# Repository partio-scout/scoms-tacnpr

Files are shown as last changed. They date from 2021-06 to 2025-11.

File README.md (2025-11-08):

# TACNPR project ('Neppari')

NPR-compatible (New Packet Radio) Ethernet-connected radio w/ integrated RF PA for the 70cm HAM band.
TACNPR is binary-compatible with the original design /1/ by Guillaume F4HDK.

Designed by Lasse OH3HZB & Tatu OH2EAT & Scoms team (special thanks to Mikko OH2FLO, Vili OH5GE and Tommi OH1GJV (TACBUCK design))

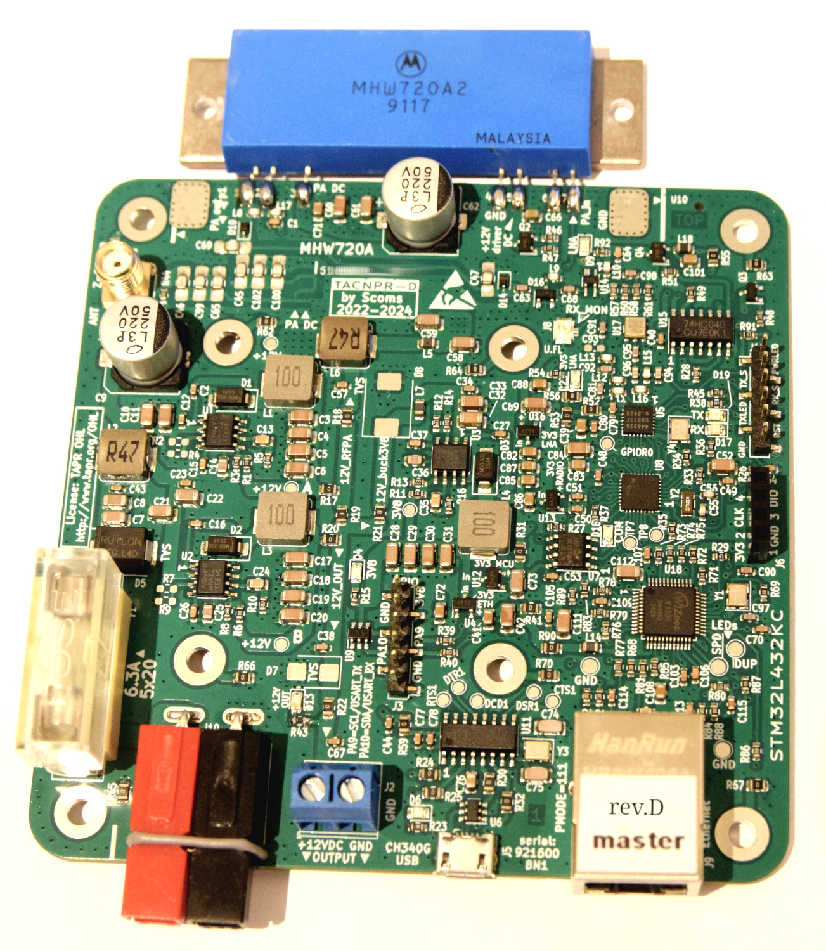
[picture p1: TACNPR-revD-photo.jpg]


Licensed under the TAPR Open Hardware License www.tapr.org/OHL

Please note that you need to be licensed HAM radio operator to use this radio. Remember to check your local regulations.

### Modifications for revA and revB to optimize RF performance

(these modifications are included in revC)

* C65 and C102: replace by 6p8
* C100: replace by 8p2

The tuning stub in revA/revB should be shorted according to the revC/revD layout.

### Project milestones and current status

* RevA: First version with Ethernet add-on module.
* RevB: Integrated Ethernet.
* RevC: RF performance enhancements (see the previous chapter). 
* RevD: Powerpole connector option added.
* RevE: TX/RX LEDs (J4)

RevC and RevD are tested and fully functional. RevA & RevB require tuning (stub) and modifications mentioned above. RevD->revE, no changes to RF section.

### Recommended TX power setting for maximum power with this PA module

set RF_power 55

/1/: NPR by Guillaume F4HDK (2018-): https://hackaday.io/project/164092-npr-new-packet-radio 

### Disclaimer

This design and all related material is provided as-is and is to be used at your own risk. The authors take no responsibility for any direct, indirect, incidental, or consequential 
damage that may arise from its use, including but not limited to damage to property, loss of data, or personal injury. Users are solely responsible for 
ensuring safe operation and adherence to all relevant laws and regulations. 

For the license terms, please refer to LICENSE file or http://www.tapr.org/OHL

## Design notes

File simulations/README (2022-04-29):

Qucs simulations for parts of the circuit

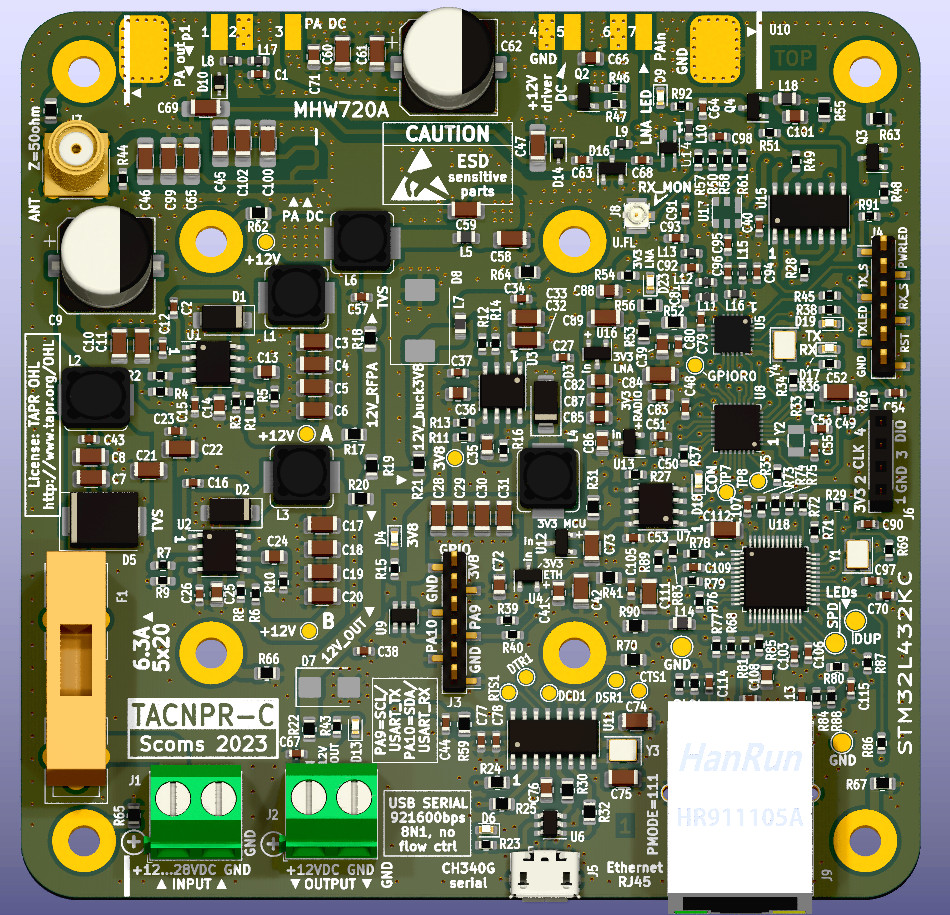
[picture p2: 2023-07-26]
TACNPR-revC-3D-top.jpg

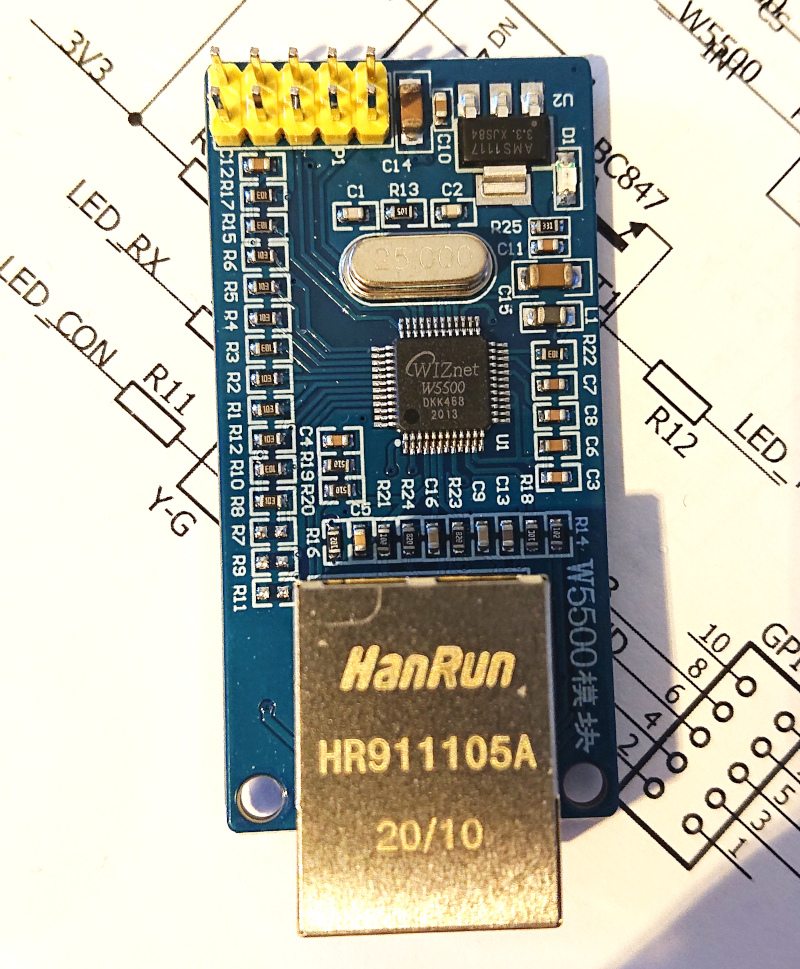
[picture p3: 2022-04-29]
w5500-module-photo-TACNPR-revA.JPG

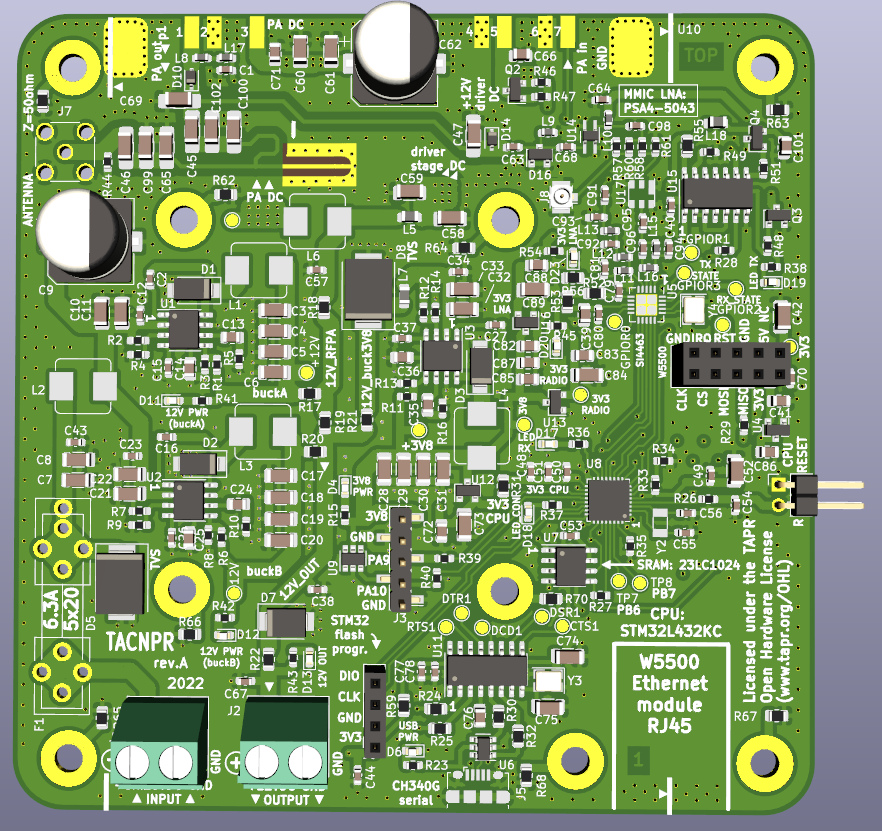
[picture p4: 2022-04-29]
TACNPR-revA-3D-top.jpg

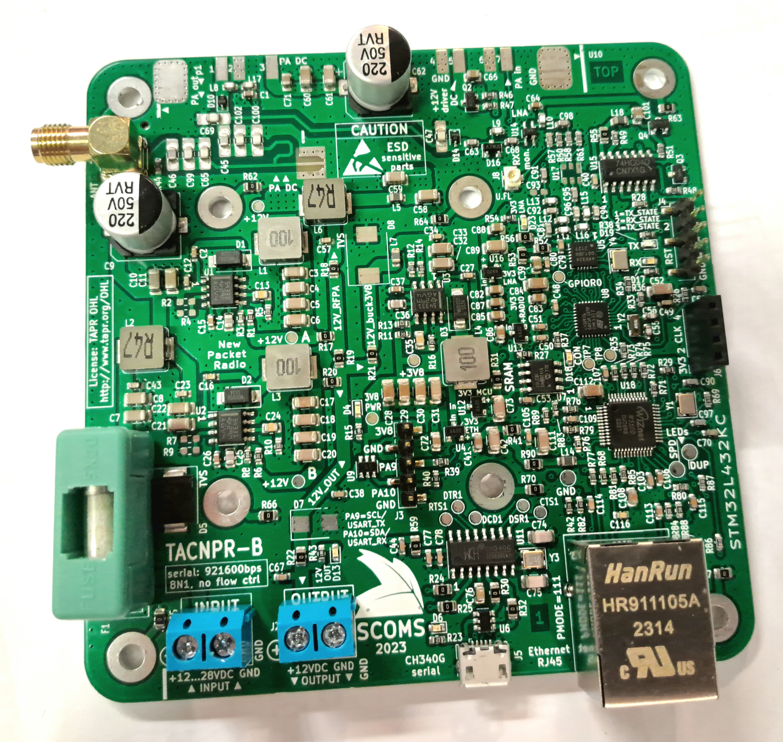
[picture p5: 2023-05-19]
TACNPR-revB-photo.jpg

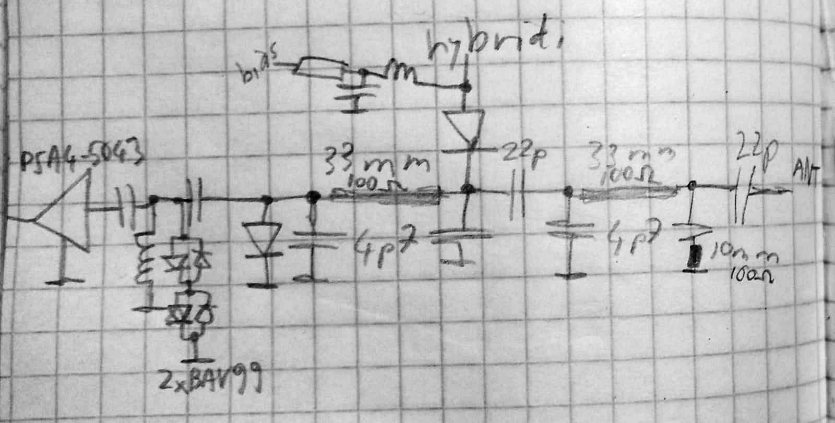
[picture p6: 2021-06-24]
rf-schema-oh2eat.jpg

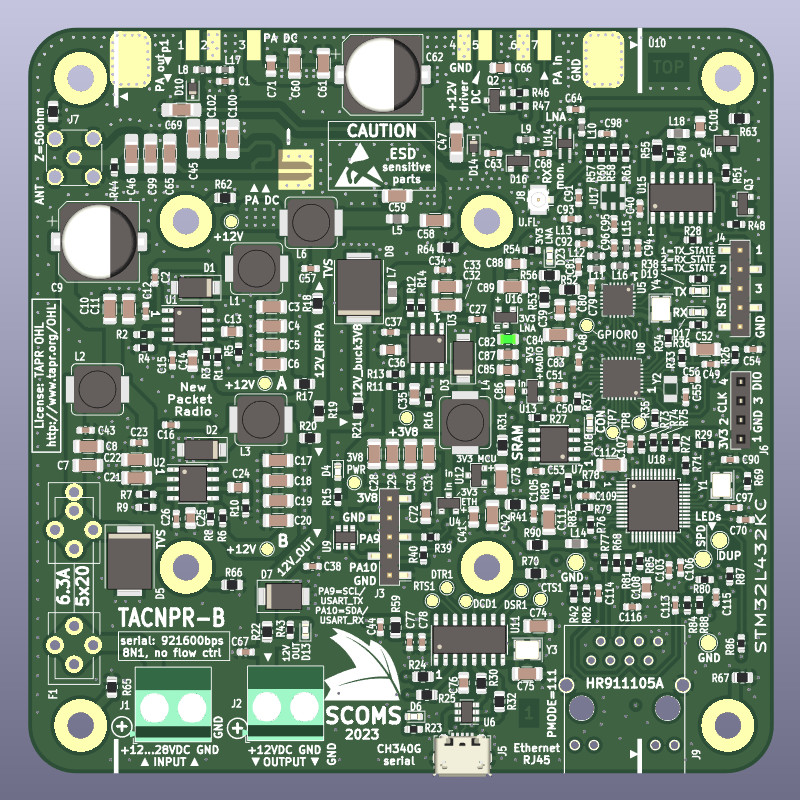
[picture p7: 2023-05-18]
TACNPR-revB-3D-top.jpg

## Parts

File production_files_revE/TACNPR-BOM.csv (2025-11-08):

Comment | Designator | Footprint | LCSC
8p2 | C100 | NPR:C_1206_0805_WIDE | C519996
4u7 | C108 | Capacitor_SMD:C_0805_2012Metric | C1779
6.8n | C114,C115 | Capacitor_SMD:C_0603_1608Metric | C1631
22n | C116 | Capacitor_SMD:C_0603_1608Metric | C21122
1n | C13,C24 | Capacitor_SMD:C_0805_2012Metric | C46653
10p | C14,C25,C36 | Capacitor_SMD:C_0805_2012Metric | C318752
10n | C1,C15,C26,C37,C64,C106,C113 | Capacitor_SMD:C_0603_1608Metric | C57112
22u | C3,C4,C5,C6,C17,C18,C19,C20,C28,C29,C30,C31,C42,C58,C59,C60,C61,C73,C84,C89 | Capacitor_SMD:C_1206_3216Metric | C12891
2n2 | C35 | Capacitor_SMD:C_0805_2012Metric | C1728
1u | C39,C41,C66,C71,C72,C82,C83,C85,C86,C87,C88,C101 | Capacitor_SMD:C_0805_2012Metric | C28323
100n | C2,C12,C16,C23,C27,C34,C38,C40,C43,C44,C48,C49,C50,C51,C53,C54,C57,C67,C70,C77,C78,C79,C80,C103,C105,C107,C109 | Capacitor_SMD:C_0603_1608Metric | C14663
10p | C45,C46 | NPR:C_1206_0805_WIDE | C597259
5p6 | C47,C69,C99 | NPR:C_1206_0805_WIDE | C513555
10u | C7,C8,C10,C11,C21,C22,C32,C33,C52,C111,C112 | Capacitor_SMD:C_1206_3216Metric | C13585
4p3 | C55,C56 | Capacitor_SMD:C_0603_1608Metric | C519108
6p8 | C65,C102 | NPR:C_1206_0805_WIDE | C519942
22p | C74,C75 | Capacitor_SMD:C_1206_3216Metric | C313096
470n | C76 | Capacitor_SMD:C_0805_2012Metric | C13967
100p | C81,C91,C95,C98 | Capacitor_SMD:C_0603_1608Metric | C14858
220u | C9,C62 | Capacitor_SMD:CP_Elec_10x10.5 | C125977
18p | C90,C97 | Capacitor_SMD:C_0603_1608Metric | C1647
10p | C63,C68,C92 | Capacitor_SMD:C_0603_1608Metric | C1634
DNP | C93 | Capacitor_SMD:C_0603_1608Metric_Pad1.08x0.95mm_HandSolder
3p3 | C94,C96 | Capacitor_SMD:C_0603_1608Metric | C1660
TestPoint | CTS1,DCD1,DSR1,DTR1,RTS1,TP7,TP8,TP10,TP12 | TestPoint:TestPoint_Pad_D1.5mm
SS34 | D1,D2,D3 | Diode_SMD:D_SMA | C8678
BA591 | D10,D14 | Diode_SMD:D_SOD-323 | C139448
BAV99 | D16 | Package_TO_SOT_SMD:SOT-23 | C2500
TX_LED | D19 | LED_SMD:LED_0805_2012Metric | C84256
3V3_LNA | D23 | LED_SMD:LED_0805_2012Metric | C2297
SMCJ28A | D5 | Diode_SMD:D_SMC | C10250
LED | D4,D6,D9,D13,D17,D18 | LED_SMD:LED_0805_2012Metric | C2297
TVS DIODE | D7 | Diode_SMD:D_SMB
TVS DIODE | D8 | Diode_SMD:D_SMC
5x20 fuse 6.3A | F1 | NPR:Fuseholder5x20_H_universal | C58066
GPIO_R1 | GPIOR0 | TestPoint:TestPoint_Pad_D1.5mm
MH | H1,H2,H3,H4,H5,H6,H7,H8 | MountingHole:MountingHole_3.5mm_Pad_TopBottom
PWR_TERM | J1,J2 | TerminalBlock_Phoenix:TerminalBlock_Phoenix_MKDS-1,5-2_1x02_P5.00mm_Horizontal | C474881
Powerpole | J10 | NPR:PowerPole_PP45_1336G1_1x2_Horizontal
GPIO_HEADER | J3 | Connector_PinHeader_2.54mm:PinHeader_1x06_P2.54mm_Vertical_SMD_Pin1Left | C5160789
GPIOR_HEADER | J4 | Connector_PinHeader_2.54mm:PinHeader_1x06_P2.54mm_Vertical_SMD_Pin1Left | C5160789
USB_B_Micro | J5 | Connector_USB:USB_Micro-B_Amphenol_10118194_Horizontal | C132563
PROG_CONN | J6 | Connector_PinSocket_2.54mm:PinSocket_1x04_P2.54mm_Vertical | C124413
SMA_F | J7 | Connector_Coaxial:SMA_Amphenol_132134_Vertical | C496549
U.fl | J8 | Connector_Coaxial:U.FL_Hirose_U.FL-R-SMT-1_Vertical | C88374
HR911105A | J9 | NPR:HR911105a | C12074
10u | L1,L3,L4 | Inductor_SMD:L_Bourns_SRP7028A_7.3x6.6mm | C132141
150n | L8,L10,L11,L17 | Inductor_SMD:L_0603_1608Metric | C15566
22n | L12 | Inductor_SMD:L_0603_1608Metric | C12099
15n | L9,L13 | Inductor_SMD:L_0603_1608Metric | C23651
47n | L15,L16 | Inductor_SMD:L_0603_1608Metric | C29683
470n | L2,L6 | Inductor_SMD:L_Bourns_SRP7028A_7.3x6.6mm | C285802
GZ2012D101TF | L5,L7,L14,L18 | Inductor_SMD:L_0805_2012Metric | C1015
10mm | NT1 | NetTie:NetTie-2_SMD_Pad0.5mm
2,5mm | NT2 | NPR:NetTie-2_longer_SMD_Pad0.5mm
10,5mm | NT3 | NetTie:NetTie-2_SMD_Pad0.5mm
AO3401A | Q2,Q4 | Package_TO_SOT_SMD:SOT-23 | C15127
MMBT3904 | Q3 | Package_TO_SOT_SMD:SOT-23 | C20526
10k 1% | R1,R6,R11 | Resistor_SMD:R_0603_1608Metric | C25804
330k | R12 | Resistor_SMD:R_0603_1608Metric | C23137
2k7 | R13 | Resistor_SMD:R_0603_1608Metric | C13167
100k | R14,R44 | Resistor_SMD:R_0603_1608Metric | C25803
DNP | R2,R4,R7,R9 | Resistor_SMD:R_0603_1608Metric_Pad0.98x0.95mm_HandSolder
1.5k | R15,R23,R36,R37,R38,R49,R54,R92 | Resistor_SMD:R_0603_1608Metric | C118397
330 | R26,R27,R29,R45,R91,R93,R94 | Resistor_SMD:R_0603_1608Metric | C23138
68 | R28,R57 | Resistor_SMD:R_0603_1608Metric | C27592
715R | R3,R8 | Resistor_SMD:R_0603_1608Metric | C23238
10k | R16,R33,R34,R35,R46,R47,R48,R51,R71,R72,R73,R74,R75 | Resistor_SMD:R_0603_1608Metric | C25804
100 1% | R39,R40,R42,R68,R81,R82,R83,R84,R88,R89 | Resistor_SMD:R_0603_1608Metric | C22775
4k7 | R43 | Resistor_SMD:R_0603_1608Metric | C23162
30k | R5,R10 | Resistor_SMD:R_0603_1608Metric | C22984
0 | R17,R18,R19,R20,R21,R22,R24,R25,R30,R31,R32,R41,R50,R52,R53,R55,R56,R59,R62,R63,R64,R65,R66,R67,R70,R90 | Resistor_SMD:R_0805_2012Metric | C17477
22 | R58 | Resistor_SMD:R_0603_1608Metric | C23345
220 | R60,R61 | Resistor_SMD:R_0603_1608Metric | C22962
1M | R69 | Resistor_SMD:R_0603_1608Metric | C22935
12.4k 1% | R76 | Resistor_SMD:R_0603_1608Metric | C227572
33 | R77,R78,R79,R80 | Resistor_SMD:R_0603_1608Metric | C23140
10 1% | R85 | Resistor_SMD:R_0603_1608Metric | C22859
1k | R86,R87 | Resistor_SMD:R_0603_1608Metric | C21190
TestPoint | TP1,TP4,TP5,TP6 | TestPoint:TestPoint_Pad_D2.0mm
BA_12V | TP11 | TestPoint:TestPoint_Pad_D1.5mm
BB_12V | TP2 | TestPoint:TestPoint_Pad_D1.5mm
BC_3V8 | TP3 | TestPoint:TestPoint_Pad_D1.5mm
CONL | TP9 | TestPoint:TestPoint_Pad_D1.5mm
TPS54331DR | U1,U2,U3 | Package_SO:SOIC-8_3.9x4.9mm_P1.27mm | C9865
MHW720A | U10 | NPR:MHW720A
CH340G | U11 | Package_SO:SOIC-16_3.9x9.9mm_P1.27mm | C14267
PSA4-5043 (SPF5043Z) | U14 | NPR:SOT-343_SC-70-4-widepad_Handsoldering | C470902
74HC04 | U15 | Package_SO:SOIC-14_3.9x8.7mm_P1.27mm | C86613
B39431B3710U410 | U17 | NPR:DCC6C
W5500 | U18 | Package_QFP:LQFP-48_7x7mm_P0.5mm | C32843
XC6206PxxxMR | U4,U12,U13,U16 | Package_TO_SOT_SMD:SOT-23 | C5446
Si4463 | U5 | Package_DFN_QFN:QFN-20-1EP_4x4mm_P0.5mm_EP2.6x2.6mm_ThermalVias | C476202
SRV05-4 | U6,U9 | Package_TO_SOT_SMD:SOT-23-6 | C85364
23LC1024 | U7 | Package_SO:SOIC-8_3.9x4.9mm_P1.27mm
STM32L432KC | U8 | Package_DFN_QFN:QFN-32-1EP_5x5mm_P0.5mm_EP3.45x3.45mm | C1337280
25 MHz | Y1 | Crystal:Crystal_SMD_3225-4Pin_3.2x2.5mm | C9006
32.768K | Y2 | Crystal:Crystal_SMD_3215-2Pin_3.2x1.5mm | C32346
12M | Y3 | Crystal:Crystal_SMD_SeikoEpson_TSX3225-4Pin_3.2x2.5mm | C9002
30M | Y4 | Crystal:Crystal_SMD_SeikoEpson_TSX3225-4Pin_3.2x2.5mm | C2149121

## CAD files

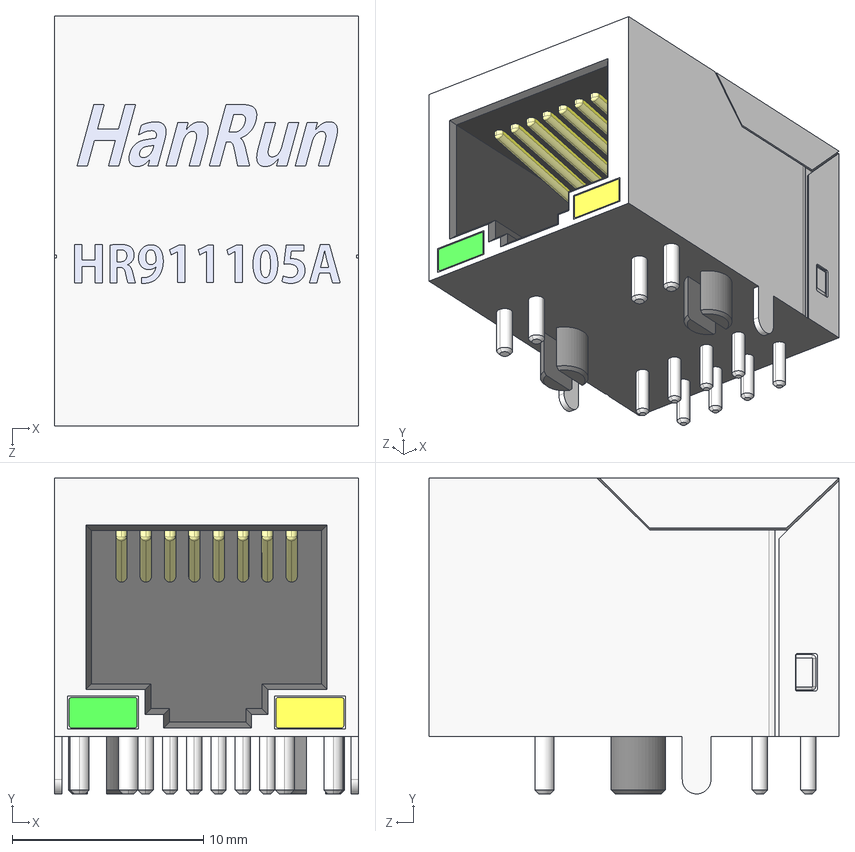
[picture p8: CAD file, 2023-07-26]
HR911105A.STEP
15.9 x 16.5 x 21.4 mm

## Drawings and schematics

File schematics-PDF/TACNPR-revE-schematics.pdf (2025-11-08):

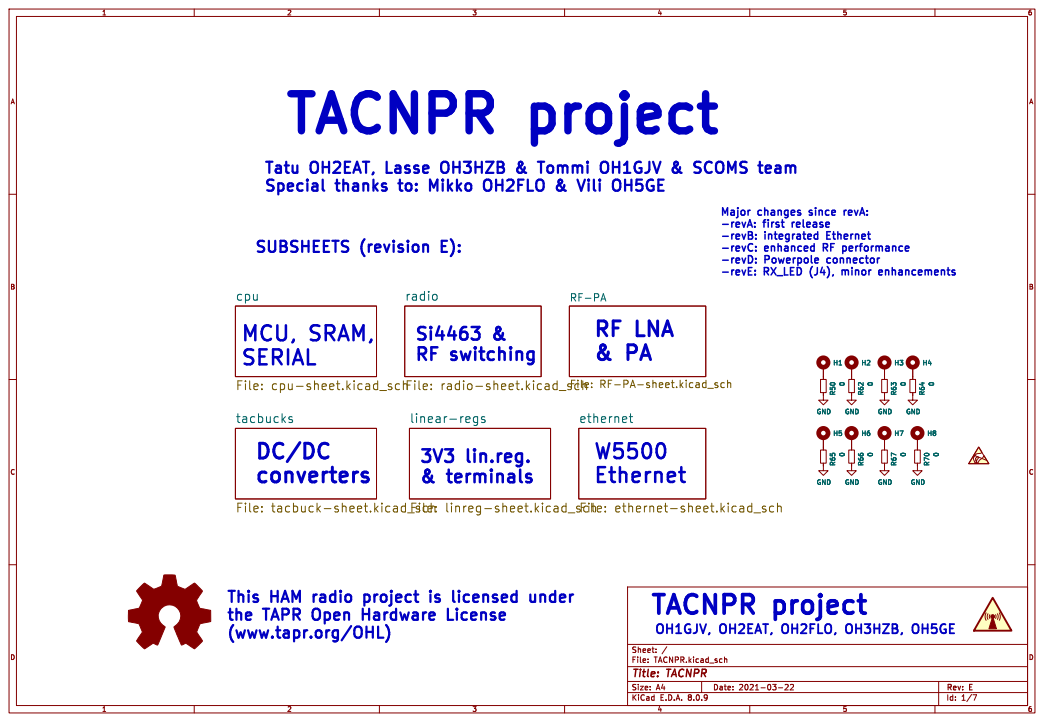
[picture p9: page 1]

Tatu OH2EAT, Lasse OH3HZB & Tommi OH1GJV & SCOMS team
Special thanks to: Mikko OH2FLO & Vili OH5GE

Major changes since revA:

File: RF-PA-sheet.kicad_sch

This HAM radio project is licensed under
the TAPR Open Hardware License
(www.tapr.org/OHL)

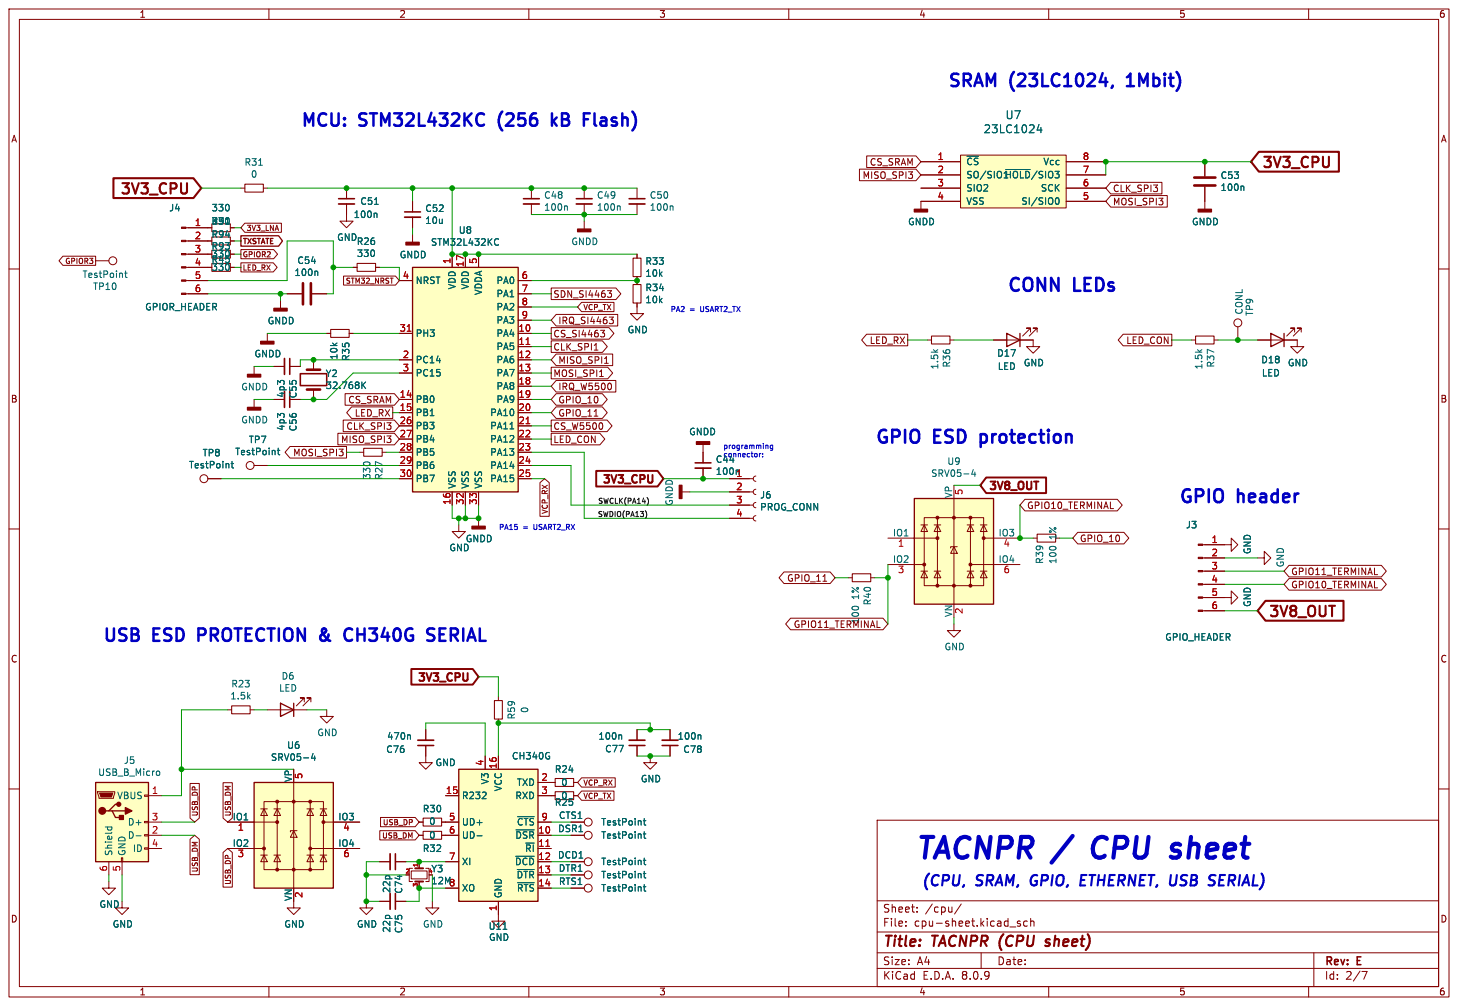
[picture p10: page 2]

1 PA4 10 PA5 11 PA6 12 PA7 13 PB0 14 PB1 15 VSS 16 VDD 17 PA8 18 PA9 19 PC14 2 PA10 20 PA11 21 PA12 22 PA13 23 PA14 24 PA15 25 PB3 26 PB4 27 PB5 28 PB6 29 PC15 3 PB7 30 PH3 31 VSS 32 VSS 33 NRST 4 VDDA

connector: PA2 = USART2_TX USB ESD PROTECTION & CH340G SERIAL

4 UD+ 5 UD- 6 XI 7 XO 8 ~{CTS}9 U11 CH340G
0 GND

4 UD+ 5 UD- 6 XI 7 XO 8 ~{CTS}9 R32

1 ~{DSR} 10 ~{RI} 11 ~{DCD} 12 ~{DTR} 13 ~{RTS} 14 R232 15 VCC 16 TXD 2 RXD 3 V3

Id: 2/7 Title: TACNPR (CPU sheet) File: cpu-sheet.kicad_sch Sheet: /cpu/ 1

(CPU, SRAM, GPIO, ETHERNET, USB SERIAL)

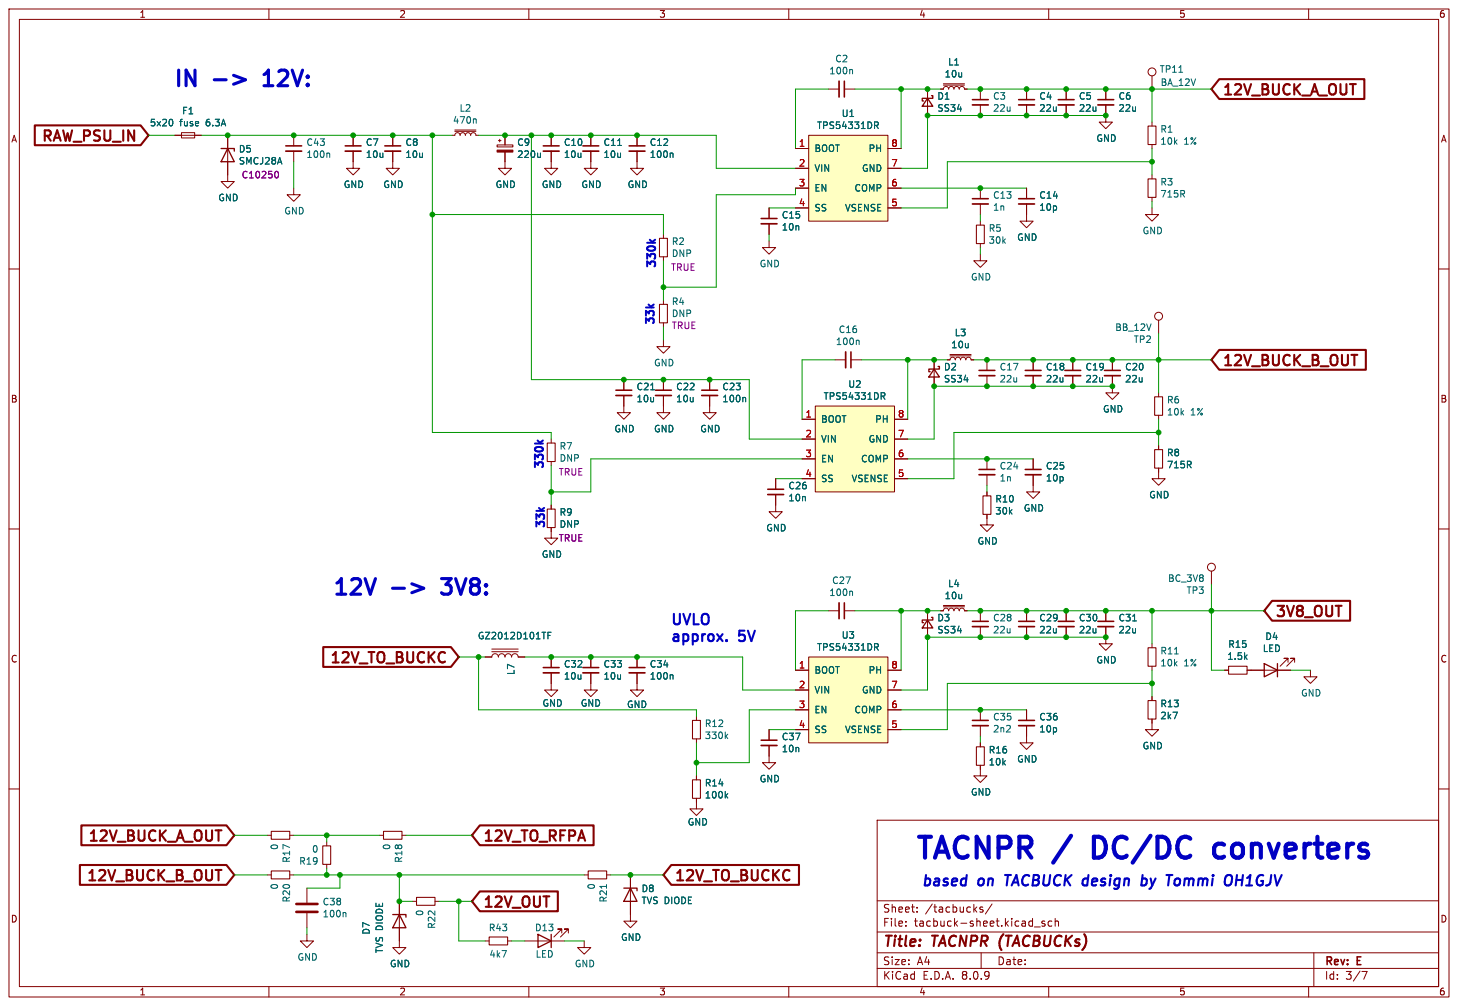
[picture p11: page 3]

TRUE GND D7 TVS DIODE GND

Id: 3/7 Title: TACNPR (TACBUCKs) File: tacbuck-sheet.kicad_sch Sheet: /tacbucks/ GND

TACNPR / DC/DC converters

based on TACBUCK design by Tommi OH1GJV

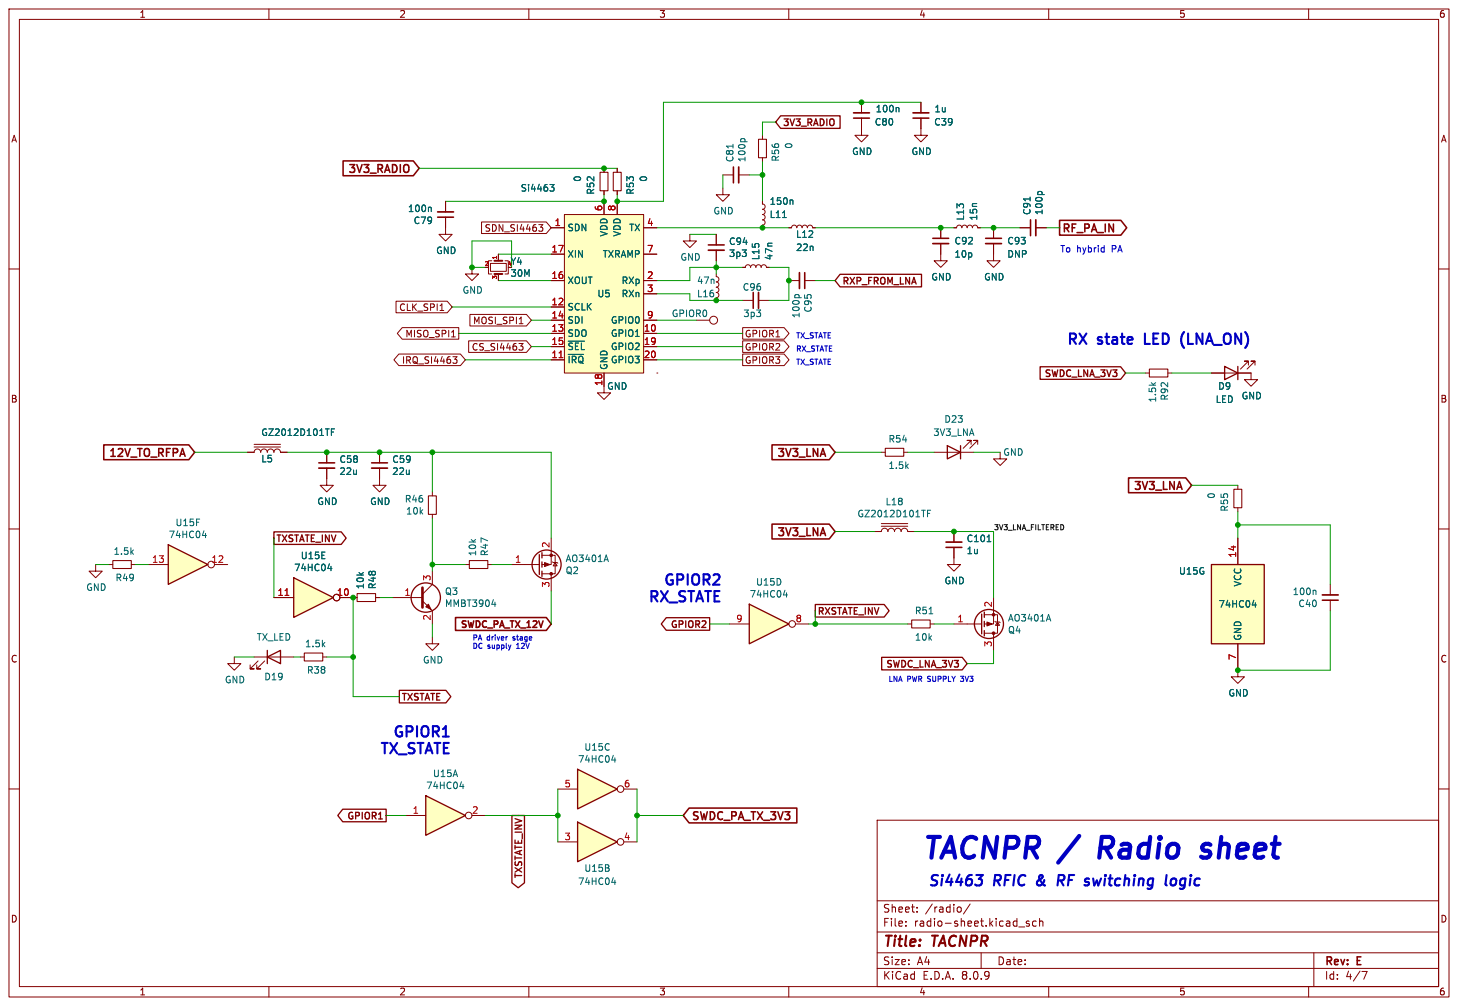
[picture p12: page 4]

File: radio-sheet.kicad_sch Sheet: /radio/ R46

Si4463 RFIC & RF switching logic

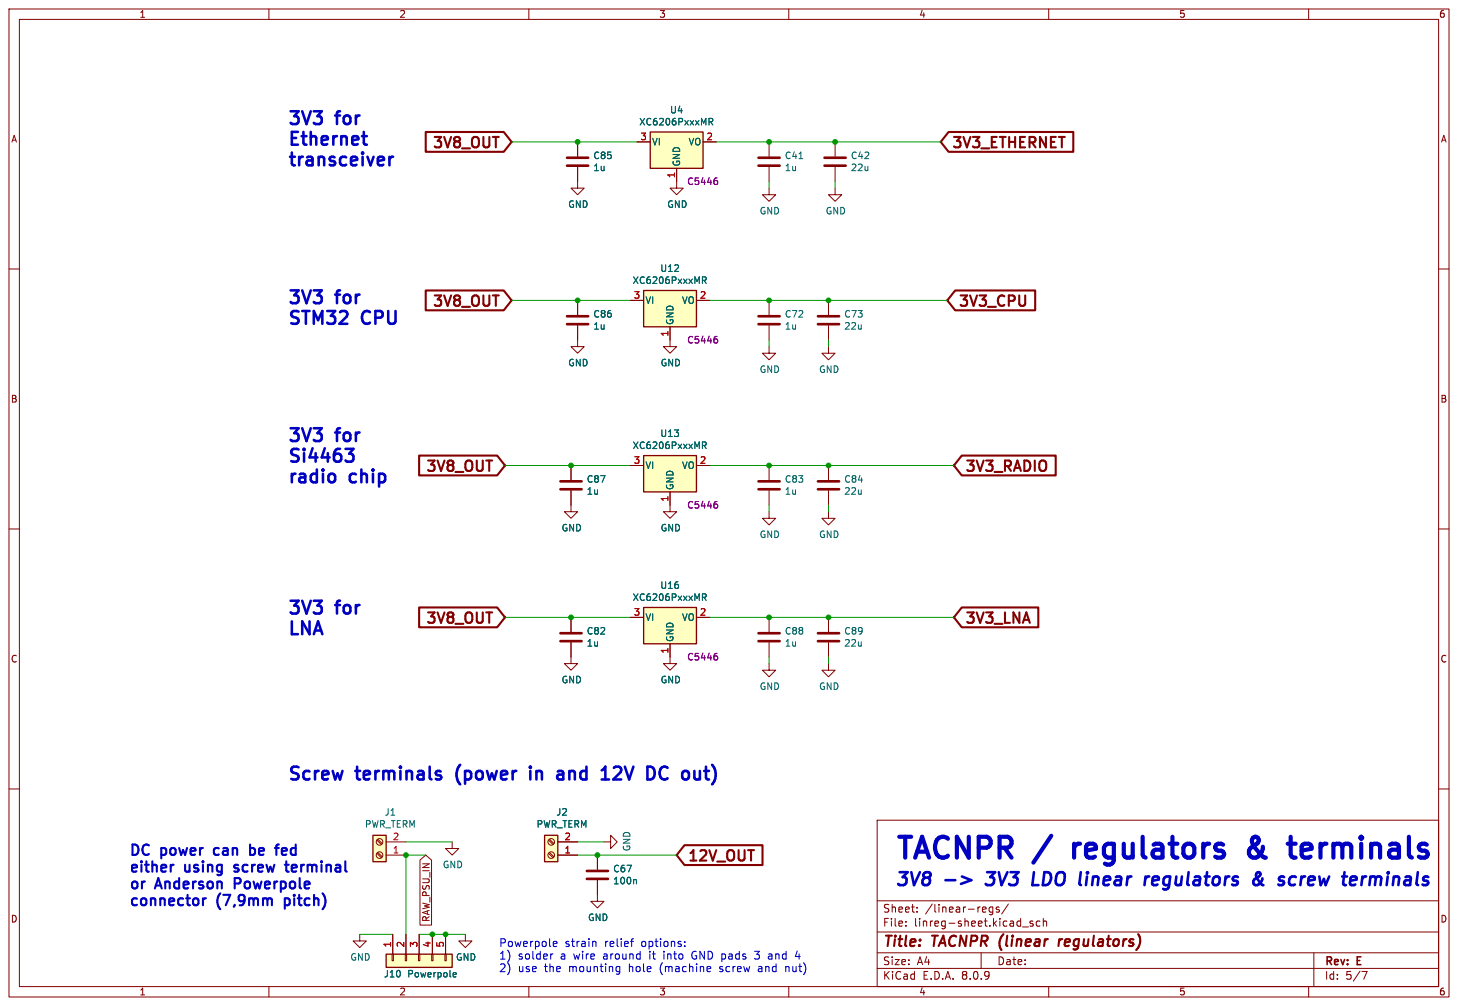
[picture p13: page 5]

1 VO 2 VI 3 GND GND
1u GND
22u GND GND

DC power can be fed
either using screw terminal or Anderson Powerpole

Id: 5/7 Title: TACNPR (linear regulators) File: linreg-sheet.kicad_sch Sheet: /linear-regs/

2) use the mounting hole (machine screw and nut) J10 Powerpole

Powerpole strain relief options:
1) solder a wire around it into GND pads 3 and 4

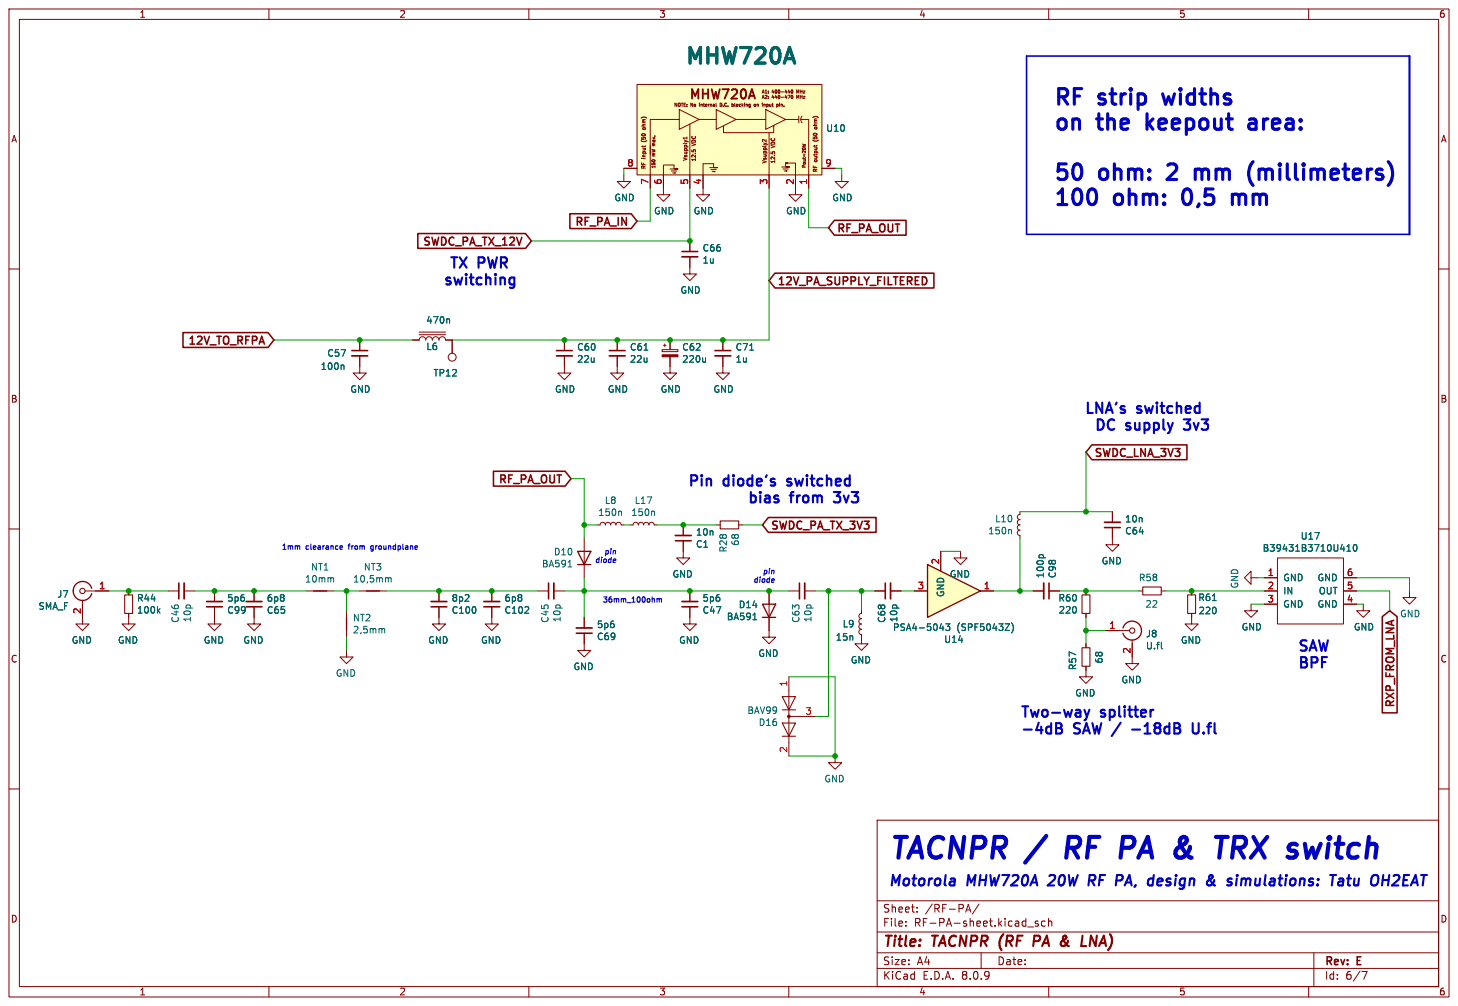
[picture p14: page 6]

RF strip widths
on the keepout area:

Id: 6/7 Title: TACNPR (RF PA & LNA) File: RF-PA-sheet.kicad_sch Sheet: /RF-PA/

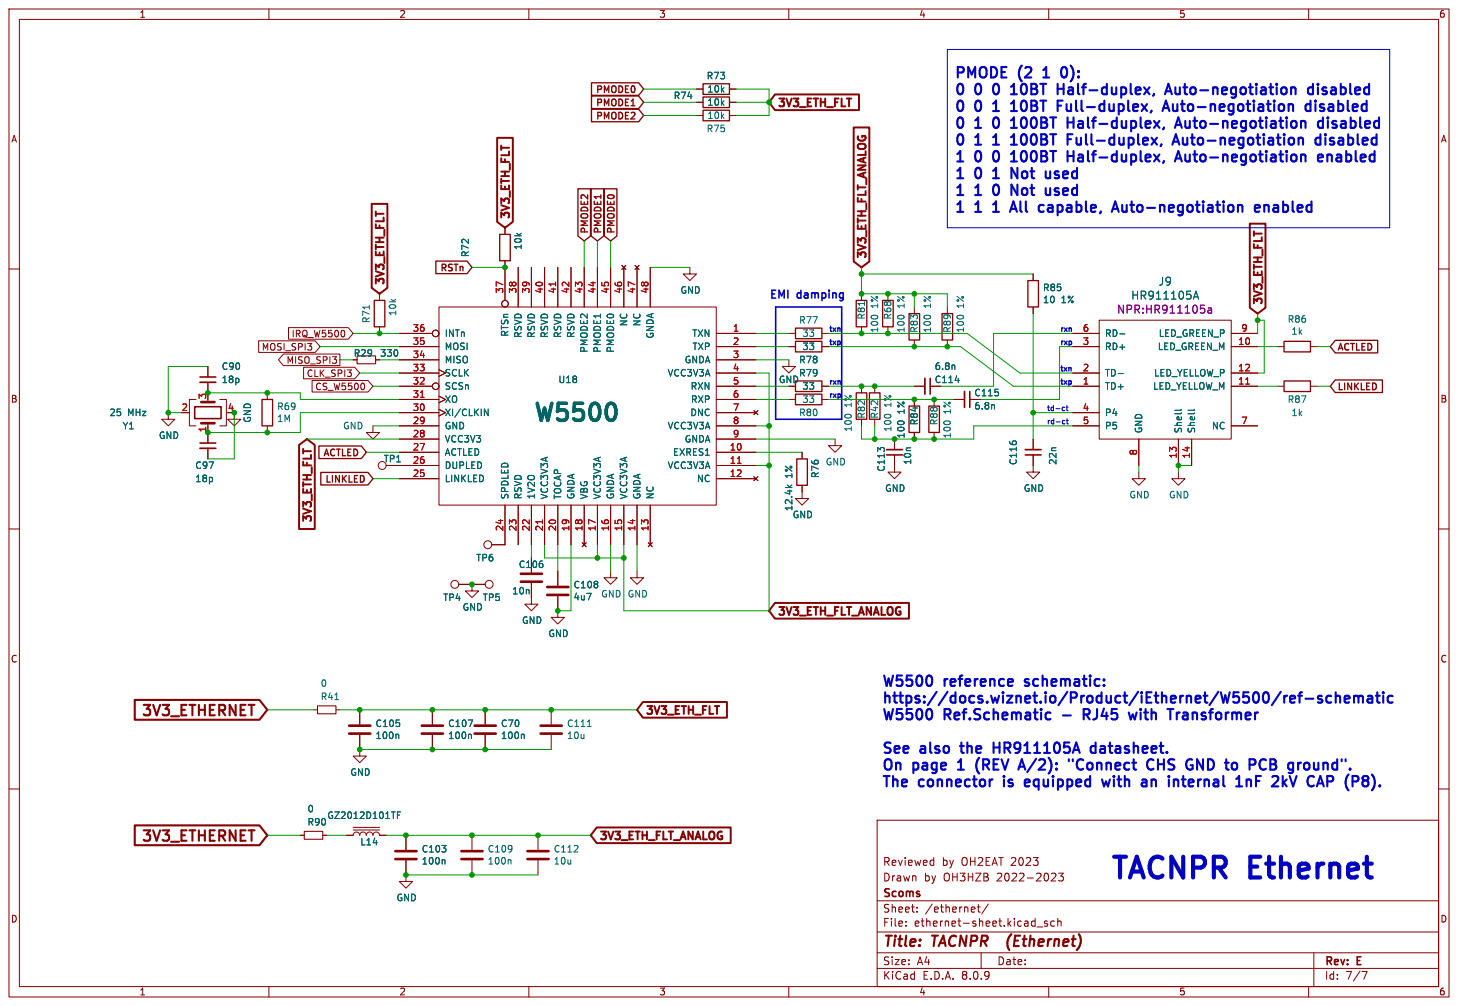
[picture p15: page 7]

td-ct rd-ct PMODE (2 1 0):
1 0 1 Not used
1 1 0 Not used

https://docs.wiznet.io/Product/iEthernet/W5500/ref-schematic

The connector is equipped with an internal 1nF 2kV CAP (P8).

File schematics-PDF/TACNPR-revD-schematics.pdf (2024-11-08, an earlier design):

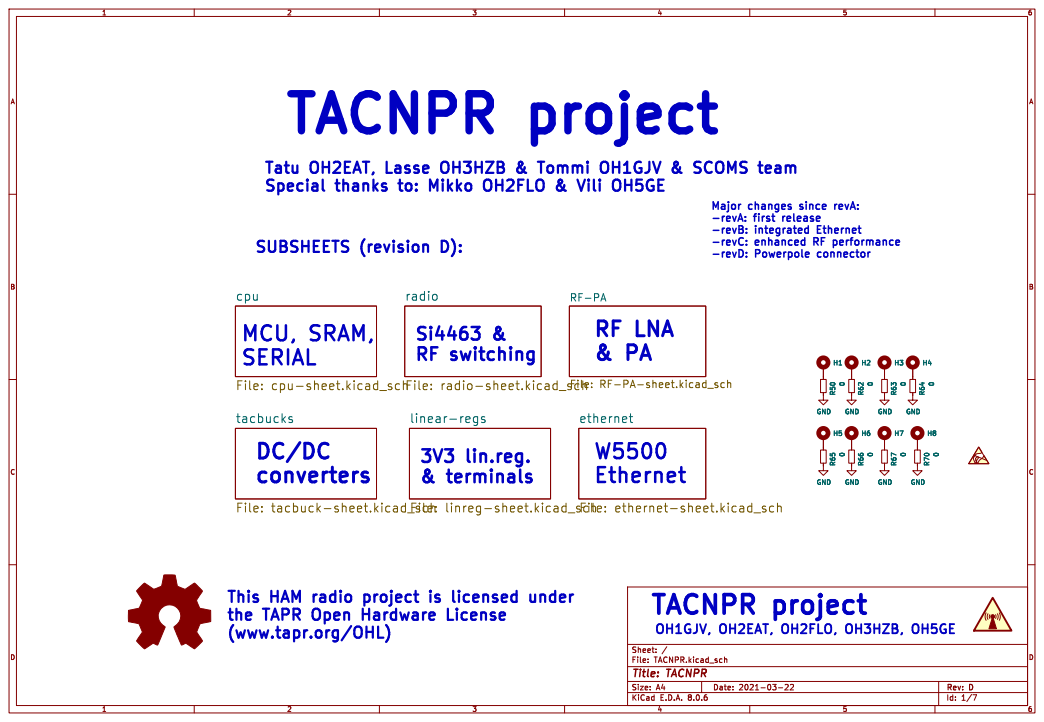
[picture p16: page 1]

Tatu OH2EAT, Lasse OH3HZB & Tommi OH1GJV & SCOMS team
Special thanks to: Mikko OH2FLO & Vili OH5GE

Major changes since revA:

File: TACNPR.kicad_sch Sheet: / cpu
MCU, SRAM,
SERIAL

File: RF-PA-sheet.kicad_sch

(www.tapr.org/OHL)

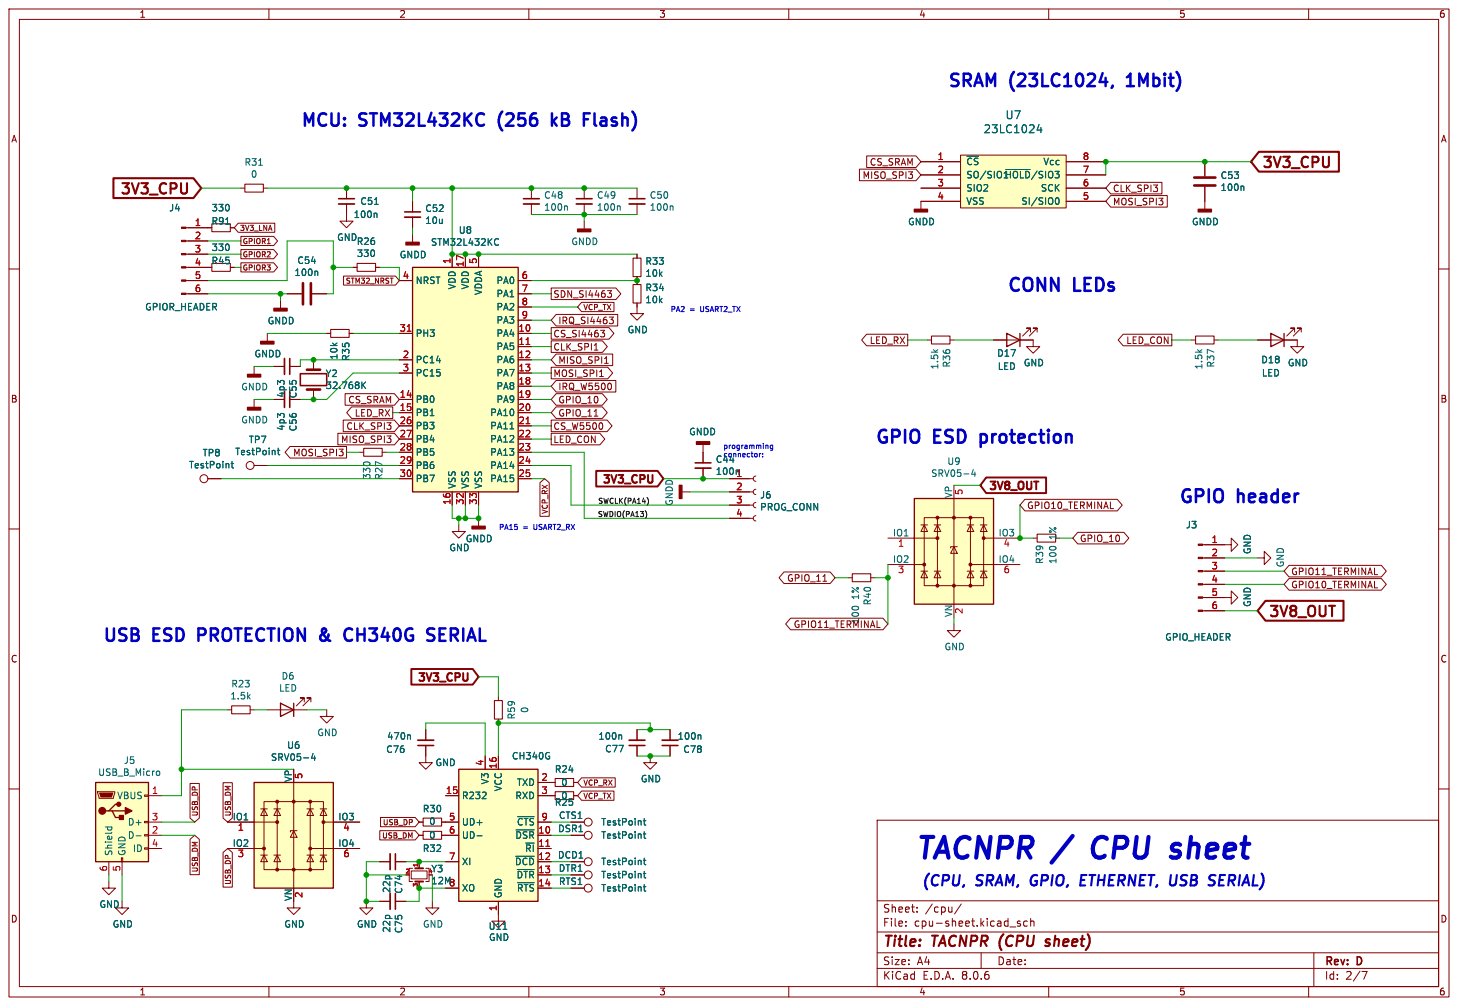
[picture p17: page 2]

1 PA4 10 PA5 11 PA6 12 PA7 13 PB0 14 PB1 15 VSS 16 VDD 17 PA8 18 PA9 19 PC14 2 PA10 20 PA11 21 PA12 22 PA13 23 PA14 24 PA15 25 PB3 26 PB4 27 PB5 28 PB6 29 PC15 3 PB7 30 PH3 31 VSS 32 VSS 33 NRST 4 VDDA

USB ESD PROTECTION & CH340G SERIAL

4 UD+ 5 UD- 6 XI 7 XO 8 ~{CTS}9 U11 CH340G
0 GND

4 UD+ 5 UD- 6 XI 7 XO 8 ~{CTS}9 GND 22p C74 22p C75 Y3

1 ~{DSR} 10 ~{RI} 11 ~{DCD} 12 ~{DTR} 13 ~{RTS} 14 R232 15 VCC 16 TXD 2 RXD 3 V3

Id: 2/7 Title: TACNPR (CPU sheet) File: cpu-sheet.kicad_sch Sheet: /cpu/ R24

(CPU, SRAM, GPIO, ETHERNET, USB SERIAL)

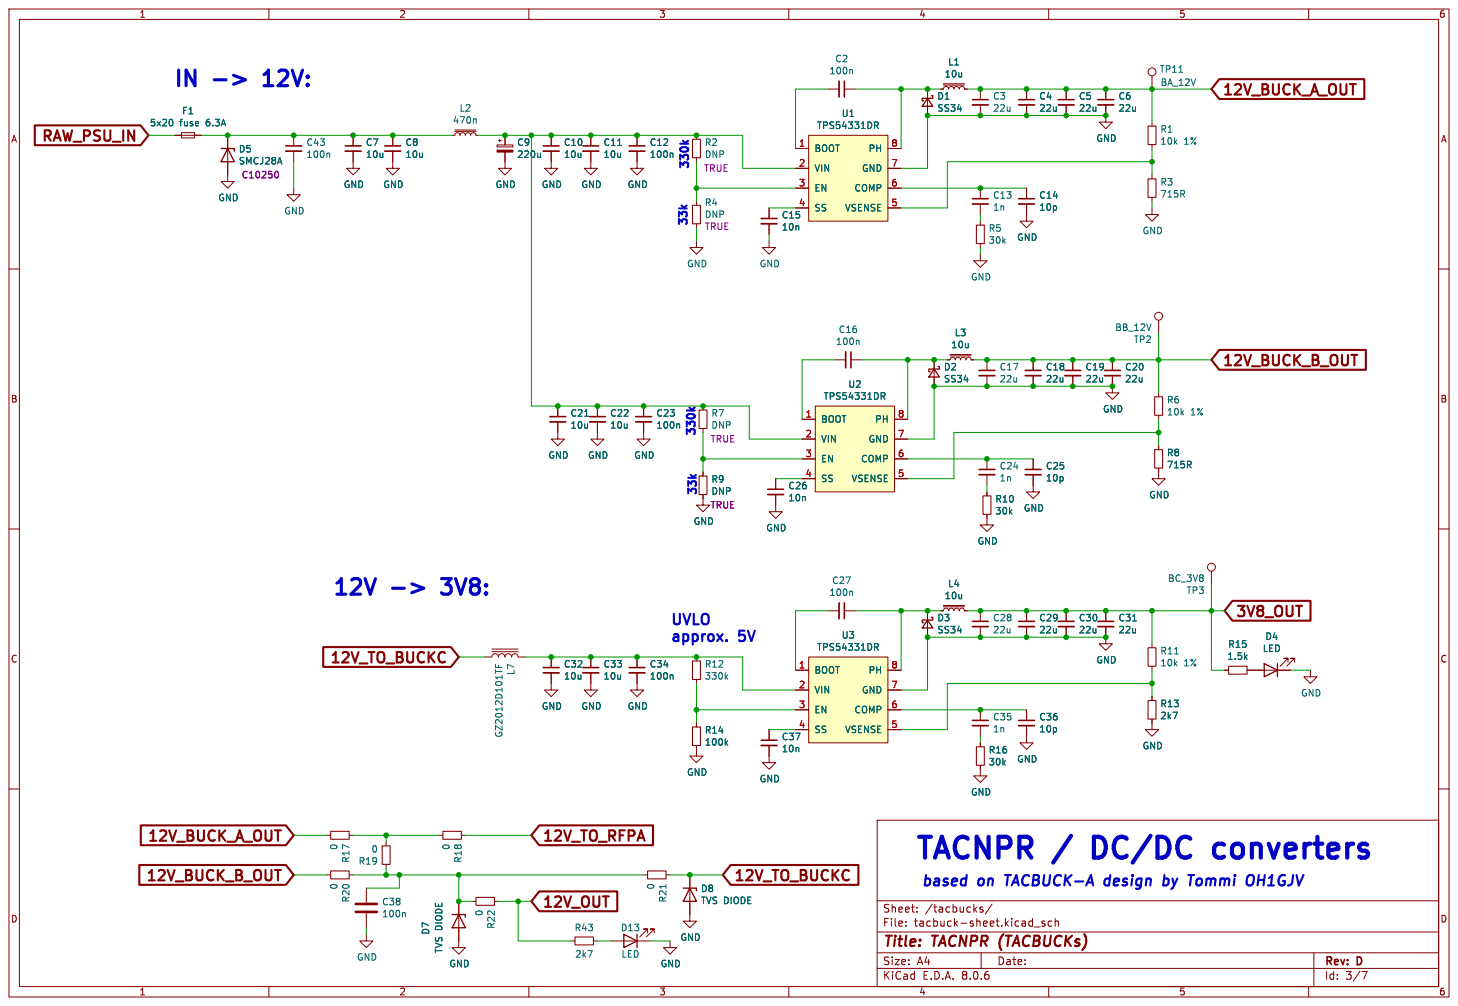
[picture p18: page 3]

TACNPR / DC/DC converters

based on TACBUCK-A design by Tommi OH1GJV

Id: 3/7 Title: TACNPR (TACBUCKs) File: tacbuck-sheet.kicad_sch Sheet: /tacbucks/

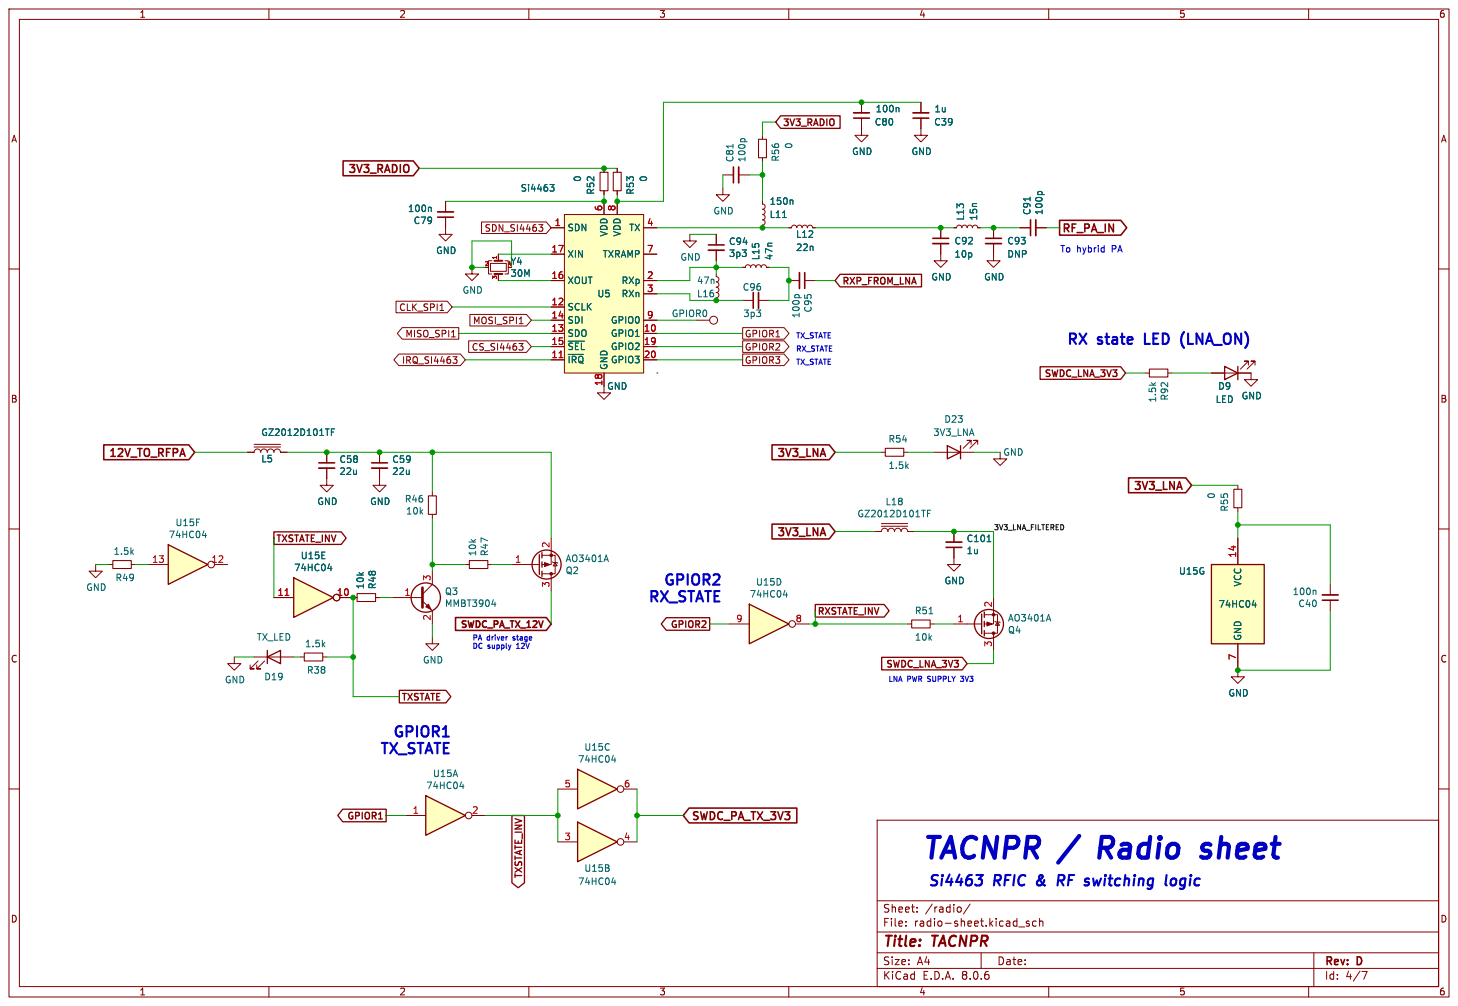
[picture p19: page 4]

File: radio-sheet.kicad_sch Sheet: /radio/ R46

Si4463 RFIC & RF switching logic

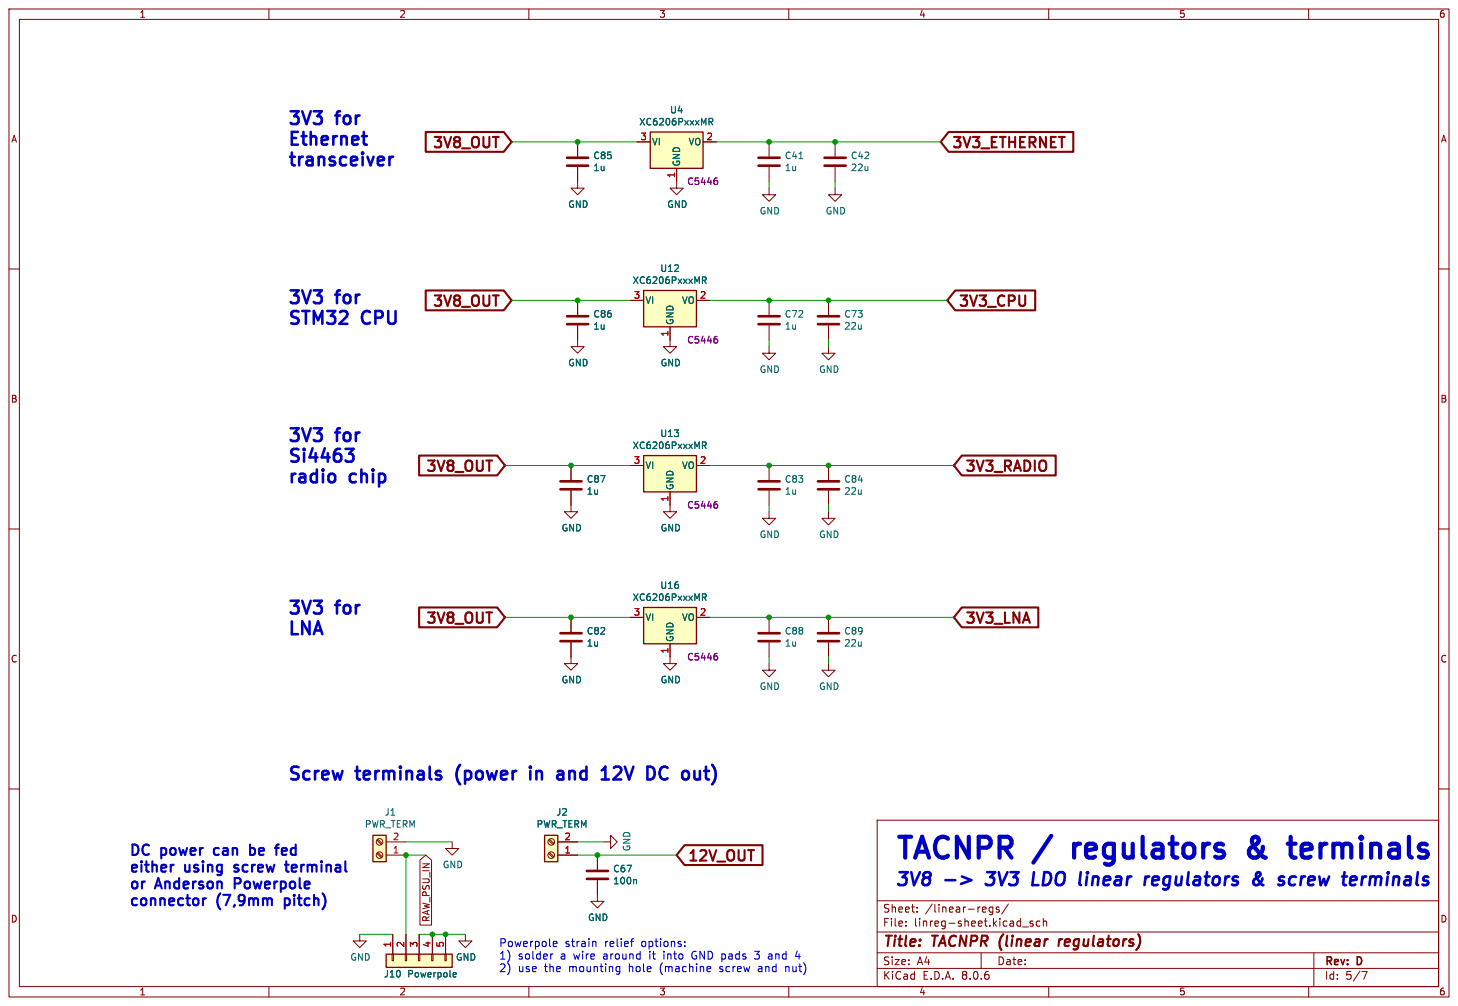
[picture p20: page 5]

1 VO 2 VI 3 GND GND
C5446 GND

DC power can be fed
either using screw terminal or Anderson Powerpole

Id: 5/7 Title: TACNPR (linear regulators) File: linreg-sheet.kicad_sch Sheet: /linear-regs/

2) use the mounting hole (machine screw and nut) J10 Powerpole

Powerpole strain relief options:
1) solder a wire around it into GND pads 3 and 4


RF strip widths
on the keepout area:

TACNPR / RF PA & TRX switch


td-ct rd-ct PMODE (2 1 0):
1 0 1 Not used
1 1 0 Not used

https://docs.wiznet.io/Product/iEthernet/W5500/ref-schematic

The connector is equipped with an internal 1nF 2kV CAP (P8).

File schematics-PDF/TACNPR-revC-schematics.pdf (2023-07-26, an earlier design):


File: RF-PA-sheet.kicad_sch

(www.tapr.org/OHL)


1 PA4 10 PA5 11 PA6 12 PA7 13 PB0 14 PB1 15 VSS 16 VDD 17 PA8 18 PA9 19 PC14 2 PA10 20 PA11 21 PA12 22 PA13 23 PA14 24 PA15 25 PB3 26 PB4 27 PB5 28 PB6 29 PC15 3 PB7 30 PH3 31 VSS 32 VSS 33 NRST 4 VDDA

USB ESD PROTECTION & CH340G SERIAL

4 UD+ 5 UD- 6 XI 7 XO 8 ~{CTS}9 U11 CH340G
0 GND

4 UD+ 5 UD- 6 XI 7 XO 8 ~{CTS}9 GND 22p C74 22p C75 Y3

1 ~{DSR} 10 ~{RI} 11 ~{DCD} 12 ~{DTR} 13 ~{RTS} 14 R232 15 VCC 16 TXD 2 RXD 3 V3

Id: 2/7 Title: TACNPR (CPU sheet) File: cpu-sheet.kicad_sch Sheet: /cpu/ R24

(CPU, SRAM, GPIO, ETHERNET, USB SERIAL)


TACNPR / DC/DC converters

based on TACBUCK-A design by Tommi OH1GJV


File: radio-sheet.kicad_sch Sheet: /radio/ R46

Si4463 RFIC & RF switching logic


1 VO 2 VI 3 GND GND
1u GND GND

Id: 5/7 Title: TACNPR (linear regulators) File: linreg-sheet.kicad_sch Sheet: /linear-regs/


RF strip widths
on the keepout area:

TACNPR / RF PA & TRX switch


td-ct rd-ct PMODE (2 1 0):
1 0 1 Not used
1 1 0 Not used

https://docs.wiznet.io/Product/iEthernet/W5500/ref-schematic

The connector is equipped with an internal 1nF 2kV CAP (P8).

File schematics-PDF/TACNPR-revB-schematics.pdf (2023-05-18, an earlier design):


Tatu OH2EAT, Lasse OH3HZB & Tommi OH1GJV & SCOMS team
Special thanks to: Mikko OH2FLO & Vili OH5GE

SUBSHEETS (revB with onboard Ethernet):

File: RF-PA-sheet.kicad_sch

This HAM radio project is licensed under
the TAPR Open Hardware License
(www.tapr.org/OHL)


1 PA4 10 PA5 11 PA6 12 PA7 13 PB0 14 PB1 15 VSS 16 VDD 17 PA8 18 PA9 19 PC14 2 PA10 20 PA11 21 PA12 22 PA13 23 PA14 24 PA15 25 PB3 26 PB4 27 PB5 28 PB6 29 PC15 3 PB7 30 PH3 31 VSS 32 VSS 33 NRST 4 VDDA

USB ESD PROTECTION & CH340G SERIAL

4 UD+ 5 UD- 6 XI 7 XO 8 ~{CTS} 9 U11 CH340G

1 ~{DSR}10 ~{RI}11 ~{DCD}12 ~{DTR}13 ~{RTS}14 R232 15 VCC 16 TXD 2 RXD 3 V3

(CPU, SRAM, GPIO, ETHERNET, USB SERIAL)

File: cpu-sheet.kicad_sch
Id: 2/7 Title: TACNPR (CPU sheet)


File: tacbuck-sheet.kicad_sch Sheet: /tacbucks/ C33

TACNPR / DC/DC converters

based on TACBUCK-A design by Tommi OH1GJV

Id: 3/7 Title: TACNPR (TACBUCKs)


PA driver stage DC supply 12V

Si4463 RFIC & RF switching logic


TACNPR / regulators & terminals
3V8 -> 3V3 LDO linear regulators & screw terminals

Sheet: /linear-regs/
File: linreg-sheet.kicad_sch
Id: 5/7 Title: TACNPR (linear regulators)


RF strip widths
on the keepout area:

File: RF-PA-sheet.kicad_sch Sheet: /RF-PA/ L9

TACNPR / RF PA & TRX switch

Id: 6/7 Title: TACNPR (RF PA & LNA)


rd-ct PMODE (2 1 0):
0 0 0 10BT Half-duplex, Auto-negotiation disabled
0 0 1 10BT Full-duplex, Auto-negotiation disabled

0 1 0 100BT Half-duplex, Auto-negotiation disabled
0 1 1 100BT Full-duplex, Auto-negotiation disabled
1 0 0 100BT Half-duplex, Auto-negotiation enabled
1 0 1 Not used
1 1 0 Not used
1 1 1 All capable, Auto-negotiation enabled

W5500 reference schematic:
https://docs.wiznet.io/Product/iEthernet/W5500/ref-schematic
W5500 Ref.Schematic - RJ45 with Transformer

See also the HR911105A datasheet.
On page 1 (REV A/2): "Connect CHS GND to PCB ground".
The connector is equipped with an internal 1nF 2kV CAP (P8).

File: ethernet-sheet.kicad_sch Sheet: /ethernet/ Scoms Drawn by OH3HZB 2022-2023

Id: 7/7 Title: TACNPR (Ethernet)

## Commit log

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2021-03-25 fix typo Si4633 -> Si4463
    [TACNPR.sch, radio-sheet.sch]
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2021-03-30 si4463 is module not chip pinout in NPR, we have to be careful..
    [radio-sheet.sch]
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2021-04-01 meeting 1.4.2021 notes, Hanrun RJ45 connector added to lib, buck layout to be enhanced
    [TACNPR.kicad_pcb, TACNPR.sch, cpu-sheet.sch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]
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2021-04-03 ESD prot. comp. should be changed (jlc basic)
    [cpu-sheet.sch]
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2021-04-04 a few corrections to coil placements
    [TACNPR.kicad_pcb]
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2021-04-08 remove USB connector, pins not compatible with NPR FW
    [TACNPR.kicad_pcb, cpu-sheet.sch]
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2021-05-08 layout further, dropped PA15 OC output -- conflicts with serial
    [TACNPR.kicad_pcb, TACNPR.sch, cpu-sheet.sch]
2021-05-08 Tommi is OH1GJV, corrected to schema
    [TACNPR.sch, tacbuck-sheet.sch]
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2021-05-13 layout further + fixed error on ETH pinheader (CS_W5500 instead of CS_4463)
    [TACNPR.kicad_pcb, cpu-sheet.sch, pwrprot-sheet.sch]
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2021-05-14 linreg-sheet was missing from git, added
    [linreg-sheet.sch]
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2021-05-15 DRC corrections
    [TACNPR.kicad_pcb, pwrprot-sheet.sch]
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2021-05-23 correct 100u elko footprint
    [RF-PA-sheet.sch, TACNPR.kicad_pcb, pwrprot-sheet.sch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]
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2021-05-26 reset sw -> jumper, eth.pinheader location
    [TACNPR.kicad_pcb, cpu-sheet.sch]
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2021-05-29 part of the changes agreed in the meeting
    [TACNPR.kicad_pcb, TACNPR.sch, cpu-sheet.sch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]
2021-05-29 put back the TVS in 3V8 buck input
    [TACNPR.kicad_pcb, tacbuck-sheet.sch]
2021-06-09 gnd vias nearby inner/bottom hooks, rearranged more room for RF components
    [RF-PA-sheet.sch, TACNPR.kicad_pcb, radio-sheet.sch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]
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2021-06-10 remove pwrprot sheet (little use), moved components into buck sheet
    [RF-PA-sheet.sch, TACNPR.kicad_pcb, TACNPR.sch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]
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2021-06-24 fixed minor glitch in bottom silk
    [TACNPR.kicad_pcb]
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2021-07-08 resolved and cleaned up todo items
    [TACNPR.kicad_pcb, TACNPR.sch, cpu-sheet.sch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]
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2021-07-29 vias inside RFPA module RF ground pads etc
    [RF-PA-sheet.sch, TACNPR.kicad_pcb, cpu-sheet.sch]
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2021-09-16 tx/rx leds, 3v3 radio led, tx/rx state headers etc
    [TACNPR.kicad_pcb, TACNPR.sch, radio-sheet.sch]
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2021-10-14 replaced BJT tx_led circuit with inverter IC buff. output to save components and space
    [TACNPR.kicad_pcb, radio-sheet.sch]
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2021-10-28 meeting 2021-10-28, minor pcb mods and some todos written to schema
    [RF-PA-sheet.sch, TACNPR.kicad_pcb, radio-sheet.sch]
2021-11-09 RF input resistor, keepout fix for the stub
    [RF-PA-sheet.sch, TACNPR.kicad_pcb, radio-sheet.sch]
2021-11-11 brainwork around protection diode alignment and switched dc supply for PA driver
    [RF-PA-sheet.sch, TACNPR.kicad_pcb, radio-sheet.sch]
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2021-11-24 fixed DRC errors
    [TACNPR.kicad_pcb]
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2021-12-23 0R resistors to RFIC VDD pins, DRC errors corrected
    [TACNPR.kicad_pcb, radio-sheet.sch]
2021-12-23 minor enhancements + 0R to logic chip VCC
    [TACNPR.kicad_pcb, cpu-sheet.sch, radio-sheet.sch]
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2022-01-07 lna dc to bottom to make RF path straight
    [TACNPR.kicad_pcb]
2022-01-09 matching network values from TACTRACKER (2016-06-25), added DNP capacitor C97
    [TACNPR.kicad_pcb, radio-sheet.sch]
2022-01-09 matching network values (RX chain) from TACTRACKER, see previous commit
    [radio-sheet.sch]
2022-01-13 meeting 13.1.2022; some notes, CH340G powering corrected, tx/rx strips from rfic (tx to in2) etc
    [RF-PA-sheet.sch, TACNPR.kicad_pcb, cpu-sheet.sch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]
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2022-01-28 SAW filter component to lib and to the schema & layout
    [TACNPR.kicad_pcb, radio-sheet.sch]
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2022-01-28 last crystal footprint change, pi attenuator to rx line, misc layout enhancements
    [RF-PA-sheet.sch, TACNPR.kicad_pcb, TACNPR.sch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]
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2022-02-22 checking schematic sheets, harmonizing fonts etc. Minor enhancements to layout (vias vs. bottom traces etc)
    [RF-PA-sheet.sch, TACNPR.kicad_pcb, TACNPR.sch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]
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2022-02-24 meeting 24.2.2022; component values, some changes to packages etc
    [RF-PA-sheet.sch, TACNPR.kicad_pcb, cpu-sheet.sch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]
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2022-03-06 couple of silkscreen text fixes etc
    [TACNPR.kicad_pcb]
2022-03-17 rest of the 100nF capacitors 0805 -> 0603
    [RF-PA-sheet.sch, TACNPR.kicad_pcb, cpu-sheet.sch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]
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2022-03-20 bottom silkscreen texts away from the heatsink area
    [RF-PA-sheet.sch, TACNPR.kicad_pcb, cpu-sheet.sch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]
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2022-03-23 Add some RF circuit simulations
    These are somewhat cleaned-up and improved versions of some
    preliminary, uncommented, messy, unfinished simulations
    from almost a year ago.
    [pinswitch.sch, switch_and_filters.sch]
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2022-03-23 some inductor values and LCSC code, adjusted Ethernet placement, verified Eth module and the RF PA hybrid footprint w/ 1:1 paper print - both seems to be now OK
    [RF-PA-sheet.sch, TACNPR.kicad_pcb, radio-sheet.sch]
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2022-03-29 changed strip width to 0,3mm for RF outside keepout area and for the digital signals on In2 and Bot
    [TACNPR.kicad_pcb]
2022-03-29 a couple of silkscreen fixes (bot)
    [TACNPR.kicad_pcb]
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2022-03-29 grounding resistor also for H8 mounting hole, now all of them can be grounded (and by default are)
    [TACNPR.kicad_pcb, TACNPR.sch]
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2022-04-01 fixed tvs symbols
    [TACNPR.kicad_pcb, cpu-sheet.sch, tacbuck-sheet.sch]
2022-04-01 replaced missing schema symbols, modified RF schema
    [RF-PA-sheet.sch, TACNPR.kicad_pcb, tacbuck-sheet.sch]
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2022-04-01 moved R28 nearby the logic IC to make room for RF parts
    [RF-PA-sheet.sch, TACNPR.kicad_pcb, radio-sheet.sch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]
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2022-04-20 silk fixes, minor layout changes
    [TACNPR.kicad_pcb, tacbuck-sheet.sch]
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2022-04-20 still some silk fixes. last commit of the day
    [TACNPR.kicad_pcb]
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2022-04-28 component value changes/additions and some minor change requests from Tatu (WA msgs 20220428) done
    [RF-PA-sheet.sch, TACNPR.kicad_pcb, radio-sheet.sch]
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2022-04-28 fixed DRC issues
    [TACNPR.kicad_pcb]
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2022-04-29 RF component LCSC codes and a couple of RF layout enhancements suggested by Tatu
    [RF-PA-sheet.sch, TACNPR.kicad_pcb, radio-sheet.sch]
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2022-04-29 corrected LCSC values for R60,R61 and R58 (reviewed all of them)
    [RF-PA-sheet.sch, TACNPR.kicad_pcb]
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2022-04-29 component orientation correction
    [TACNPR-top-pos-JLC.csv]
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2022-04-29 remove TACNPR-revA-assembly-files and TACNPR-revA-gerbers (production files replace)
    [TACNPR-B_Cu.gbl, TACNPR-B_Mask.gbs, TACNPR-B_Paste.gbp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]
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2022-05-19 revA errata: corrected J4 LCSC code (was 2x4, should be 2x5)
    [cpu-sheet.sch]
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2022-10-16 integrated ethernet almost there, STM32 progr. header pins to be routed, silkscreen texts to be aligned etc
    [TACNPR.kicad_pcb]
2022-10-16 some silkscreen fixes
    [TACNPR.kicad_pcb]
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2022-10-17 fixed L symbols, enhanced layout a bit, wrote down TODOs
    [TACNPR.kicad_pcb]
2022-11-11 better place for SRAM, silk fixes and additions, other minor enhancements + committed kicad6 schema files
    [RF-PA-sheet.kicad_sch, TACNPR.kicad_pcb, TACNPR.kicad_sch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]
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2022-11-13 fixed broken schema symbols, removed buck12V output LEDs
    [RF-PA-sheet.kicad_sch, TACNPR.kicad_pcb, TACNPR.kicad_sch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]
2022-11-13 RX and TX leds together, minor layout & silk fixes etc
    [RF-PA-sheet.kicad_sch, TACNPR.kicad_pcb, TACNPR.kicad_sch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]
2022-11-13 One one was too big :), fixed
    [TACNPR.kicad_pcb]
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2022-12-10 50R to 2*100R in parallel to use JLC Basic, 2kV cap to SMD to avoid THD placement cost, silk enhancements, added missing LCSC codes
    [TACNPR.kicad_pcb, TACNPR.kicad_sch, cpu-sheet.kicad_sch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]
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2022-12-10 one more commit: removed solder paste from LNA and SAW filter (in KiCAD) as theyre going to be soldered manually
    [TACNPR.kicad_pcb]
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2023-02-08 corrected C117 in eth schema, added some labels for clarity, re-checked the eth schema
    [TACNPR.kicad_pcb, TACNPR.kicad_sch, ethernet-sheet.kicad_sch]
2023-02-08 telco 8.2.2023: eth 3v3 & 3v3a separated, C101 better placement, continuous guidelines for heat spreader, pgm conn pinout also to bottom, one wire still to be routed..
    [TACNPR.kicad_pcb, TACNPR.kicad_sch, ethernet-sheet.kicad_sch]
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2023-02-11 DRC fix + a couple of gnd vias added
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2023-02-12 bottom silk text correction (input volt range)
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2023-02-13 INT&RST pull-ups were in AVCC, should be VCC -- corrected. Schematic-PDF updated. This will be revB-rc2.
    [ethernet-sheet.kicad_sch]
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2023-03-12 PSA4-5043 -> SPF5043Z (removed silk text, added LCSC code, added paste back)
    [RF-PA-sheet.kicad_sch, TACNPR.kicad_sch]
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2023-04-26 a few corrections to LCSC codes
    [TACNPR.kicad_sch, ethernet-sheet.kicad_sch, tacbuck-sheet.kicad_sch]
2023-04-26 replaced out-of-stock components LCSC codes with new ones
    [cpu-sheet.kicad_sch, radio-sheet.kicad_sch]
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2023-07-12 RF capacitor value adjustments based on Tatus lab session 2023-07-12, LCSC codes updated accordingly
    [RF-PA-sheet.kicad_sch]
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2023-07-12 RF changes underway, next: shortened tuning stub to be grounded
    [TACNPR.kicad_pcb]
2023-07-14 PA DC supply to be filled zone on both BOT&TOP and changed U17,U10 footprints to be of SMD type
    [RF-PA-sheet.kicad_sch, TACNPR.kicad_pcb]
2023-07-14 fixed majority of DRC errors
    [RF-PA-sheet.kicad_sch, TACNPR.kicad_pcb]
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2023-07-14 A brutal way to achieve proper stub lenghts, but leaving still one DRC error.. There must be a better solution
    [RF-PA-sheet.kicad_sch, TACNPR.kicad_pcb]
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2023-07-15 added longer NetTie to NPR library even though not currently in use (didnt solve DRC error for GNDing stub)
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2023-07-22 a couple of GND vias too near to the PA DC area
    [TACNPR.kicad_pcb]
2023-07-26 revC production files, NOTE: component orientation not corrected according to JLC preview
    [TACNPR-BOM.csv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]
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2024-04-27 some corrections to dimensions
    [TACNPR.kicad_pcb]
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2024-04-30 text correction
    [TACNPR.kicad_pcb]
2024-04-30 fixed bot silk alignment for 12V out
    [TACNPR.kicad_pcb]
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2024-09-29 checked DRC and removed one problematic GND via
    [TACNPR.kicad_pcb]
2024-09-29 fixed one GND via elsewhere
    [TACNPR.kicad_pcb]
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2024-10-06 replace out-of-stock-LCSC codes with available ones
    [RF-PA-sheet.kicad_sch, tacbuck-sheet.kicad_sch]
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2024-10-06 remove values from DNP resistors to avoid accidental assembly
    [tacbuck-sheet.kicad_sch]
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2024-11-04 add resistor R93 to make RX_STATE to be RX_LED on header J4
    [TACNPR.kicad_pcb, cpu-sheet.kicad_sch]
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2025-01-03 replace RX STATE LED by RXLED on header J4, R45 added
    [TACNPR.kicad_pcb, cpu-sheet.kicad_sch]
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2025-11-08 J4 pin order correction
    [TACNPR.kicad_pcb, cpu-sheet.kicad_sch]
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
